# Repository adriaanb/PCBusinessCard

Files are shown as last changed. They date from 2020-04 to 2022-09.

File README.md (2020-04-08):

# PCBusinessCard
Another PCB Business Card, this time combining the functionality of an Arduino Leonardo with a capacitive touch interface.

The aim is to provide new contacts some insights into my passions, way of working, and creative style. It also allows me to hand out a tool I use frequently and enable people to discover its potential..

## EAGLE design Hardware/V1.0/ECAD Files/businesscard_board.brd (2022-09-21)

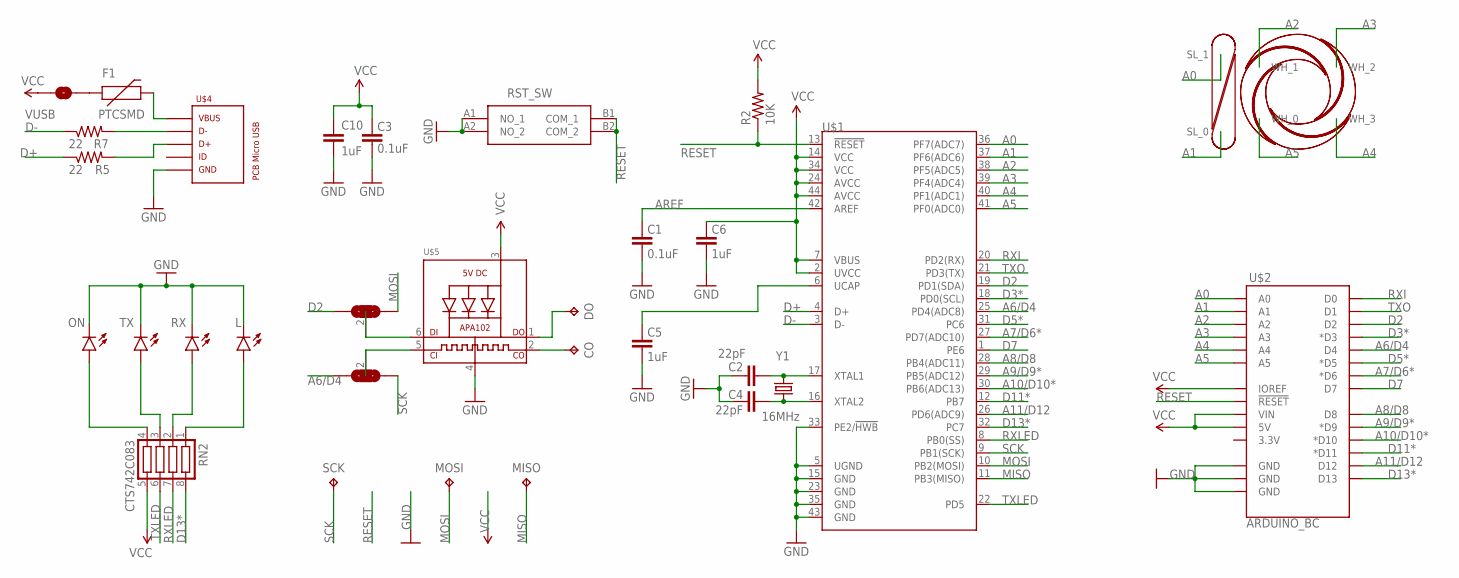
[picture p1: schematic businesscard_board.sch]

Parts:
C1, C3: 0.1uF; 0603-CAP
C2, C4: 22pF; 0603-CAP
C5, C6, C10: 1uF; 0603-CAP
CO: TPTP12R; TP12R
D2-/-°-MOSI, D4-/-°-SCK: SOLDER_JP_3WAY
DO: TPTP12R; TP12R
F1: PTCSMD; PTC-1206
L: LED; LED-0603_NOMARKER
MISO: TPTP12R; TP12R
MOSI: TPTP12R; TP12R
ON: LED; LED-0603_NOMARKER
R2: 10K; 0603-RES
R5, R7: 22; 0603-RES
RN2: CTS742C083
RST_SW: EVP-BB0AAB000; EVPBB0AAB000
RX: LED; LED-0603_NOMARKER
SCK: TPTP12R; TP12R
TX: LED; LED-0603_NOMARKER
U$1: 32U4; TQFP44_QRCODE
U$2: ARDUINO_BC; ARDUINO_BC_SINGLEROWS
U$3: TOUCH_SENSORS
U$4: PCB_MICRO_USB_B; USB_TYPE_B_SS_2_NO_DIMENSION
U$5: APA1022020; APA102_2020
VUSB: SOLDER_JP
Y1: 16MHz; CRYSTAL-SMD-5X3

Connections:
A0: U$1.36 (PF7(ADC7)), U$2.A0, U$3.SLIDER_1 (SL_1)
A1: U$1.37 (PF6(ADC6)), U$2.A1, U$3.SLIDER_0 (SL_0)
A2: U$1.38 (PF5(ADC5)), U$2.A2, U$3.WHEEL_1 (WH_1)
A3: U$1.39 (PF4(ADC4)), U$2.A3, U$3.WHEEL_2 (WH_2)
A4: U$1.40 (PF1(ADC1)), U$2.A4, U$3.WHEEL_3 (WH_3)
A5: U$1.41 (PF0(ADC0)), U$2.A5, U$3.WHEEL_0 (WH_0)
A6/D4: D4-/-°-SCK.3 (DIS), U$1.25 (PD4(ADC8)), U$2.D4
A7/D6*: U$1.27 (PD7(ADC10)), U$2.D6 (*D6)
A8/D8: U$1.28 (PB4(ADC11)), U$2.D8
A9/D9*: U$1.29 (PB5(ADC12)), U$2.D9 (*D9)
A10/D10*: U$1.30 (PB6(ADC13)), U$2.D10 (*D10)
A11/D12: U$1.26 (PD6(ADC9)), U$2.D12
APA102_CI: D4-/-°-SCK.2 (MID), U$5.5 (CKI)
APA102_CO: CO.TP, U$5.2 (CKO)
APA102_DO: DO.TP, U$5.1 (DO)
AREF: C1.2, U$1.42 (AREF)
D2: D2-/-°-MOSI.3 (DIS), U$1.19 (PD1(SDA)), U$2.D2
D3*: U$1.18 (PD0(SCL)), U$2.D3 (*D3)
D5*: U$1.31 (PC6), U$2.D5 (*D5)
D7: U$1.1 (PE6), U$2.D7
D11*: U$1.12 (PB7), U$2.D11 (*D11)
D13*: RN2.8, U$1.32 (PC7), U$2.D13
D+: R5.1, U$1.4 (D+)
D-: R7.1, U$1.3 (D-)
GND: C1.1, C2.2, C3.1, C4.2, C5.1, C6.1, C10.2, L.C, ON.C, RST_SW.A1 (NO_1), RST_SW.A2 (NO_2), RX.C, TX.C, U$1.5 (UGND), U$1.15 (GND), U$1.23 (GND), U$1.33 (PE2/!HWB), U$1.35 (GND), U$1.43 (GND), U$2.GND@1 (GND), U$2.GND@2 (GND), U$2.GND@3 (GND), U$4.5, U$5.4 (GND)
MISO: MISO.TP, U$1.11 (PB3(MISO))
MOSI: D2-/-°-MOSI.1 (CON), MOSI.TP, U$1.10 (PB2(MOSI))
unnamed: ON.A, RN2.4
unnamed: RN2.3, TX.A
unnamed: L.A, RN2.1
unnamed: RN2.2, RX.A
unnamed: F1.1, VUSB.2
unnamed: D2-/-°-MOSI.2 (MID), U$5.6 (DI)
unnamed: C4.1, U$1.16 (XTAL2), Y1.1
unnamed: C2.1, U$1.17 (XTAL1), Y1.3 (2)
unnamed: C5.2, U$1.6 (UCAP)
unnamed: R7.2, U$4.2
unnamed: R5.2, U$4.3
RESET: R2.1, RST_SW.B1 (COM_1), RST_SW.B2 (COM_2), U$1.13 (!RESET), U$2.RESET@1 (!RESET!)
RXI: U$1.20 (PD2(RX)), U$2.D0
RXLED: RN2.7, U$1.8 (PB0(SS))
SCK: D4-/-°-SCK.1 (CON), SCK.TP, U$1.9 (PB1(SCK))
TXLED: RN2.6, U$1.22 (PD5)
TXO: U$1.21 (PD3(TX)), U$2.D1
USB_PWR: F1.2, U$4.1
VCC: C3.2, C6.2, C10.1, R2.2, RN2.5, U$1.2 (UVCC), U$1.7 (VBUS), U$1.14 (VCC), U$1.24 (AVCC), U$1.34 (VCC), U$1.44 (AVCC), U$2.5V, U$2.5V@2 (VIN), U$2.IOREF, U$5.3 (VDD), VUSB.1

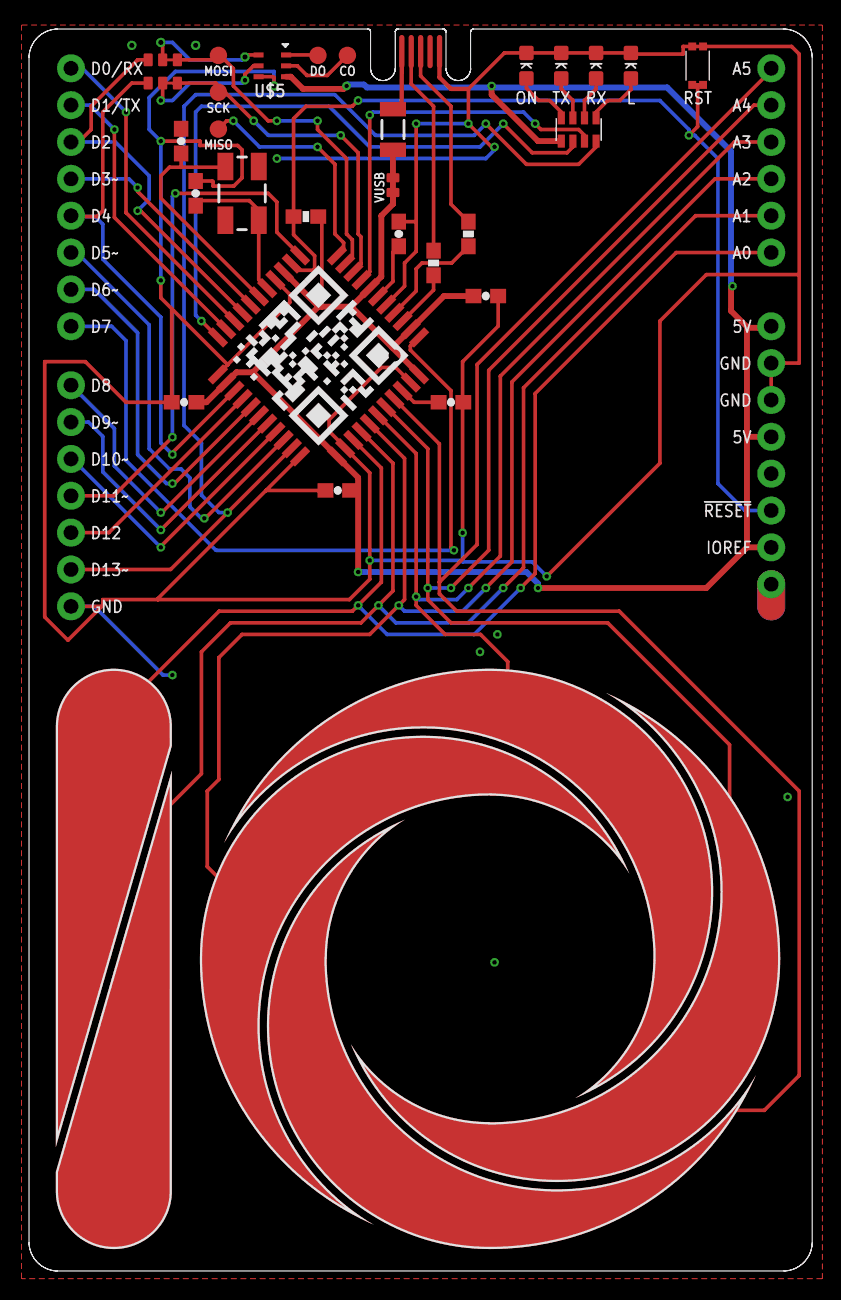
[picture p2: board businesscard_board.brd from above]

Board: 2 copper layers, 54.0 x 85.6 mm, 31 parts (0 on the bottom side), 46 nets.

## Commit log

2022-09-11 Initial commit
    Initial commit of ECAD files in preparation for next revision
    [businesscard_board.brd, businesscard_board.sch]
2022-09-21 Fix APA102 pinout
    Fix APA102 pinout, clean up library
    [businesscard_board.brd, businesscard_board.sch]
